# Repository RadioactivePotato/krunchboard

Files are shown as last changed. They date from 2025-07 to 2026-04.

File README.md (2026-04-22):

# NO LONGER UPDATE, CHECK OUT A NEWER VERSION [HERE](https://github.com/krunchiekrunch/krunchboard-90)

# krunchboard
A custom 80% ISO mechanical keyboard powered by a Raspberry Pi Pico with KMK

# Note

Prod V1 of the PCB has its I2C lines flipped for the 0.91" OLED Display and MCP23017

Firmware doesn't work yet

# About
I made this keyboard after I designed my [macropad](https://github.com/krunchiekrunch/krunchpad), and I thought this would be a fun project to do, I've also never owned a mechanical keyboard so maybe this is a good way to start?

# Images

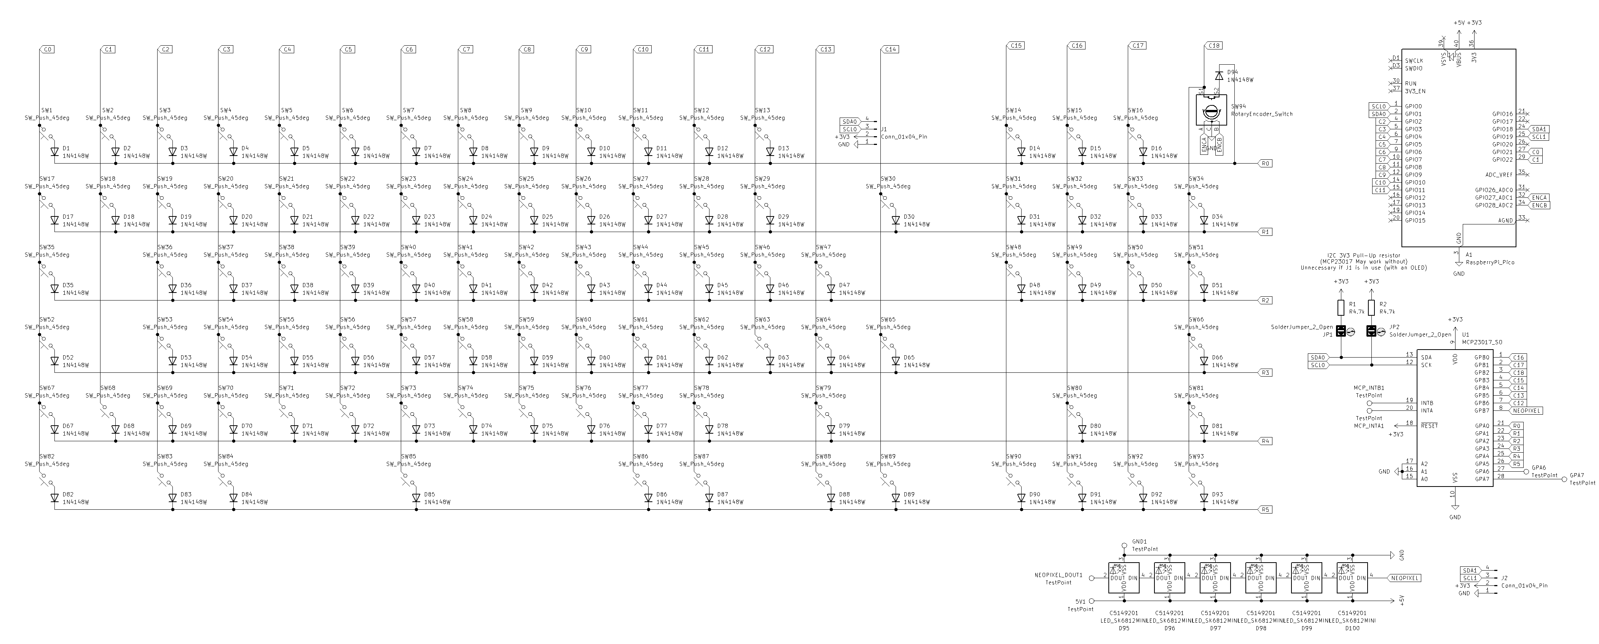
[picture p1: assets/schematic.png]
Schematic


| PCB | 3D View |
|-----|---|
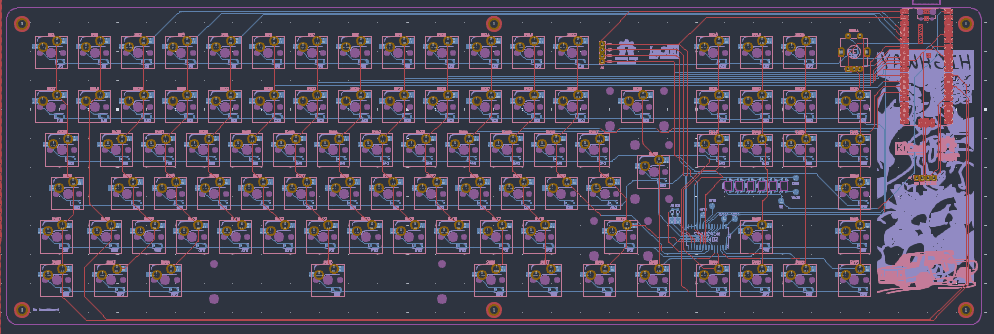
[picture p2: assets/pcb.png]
PCB
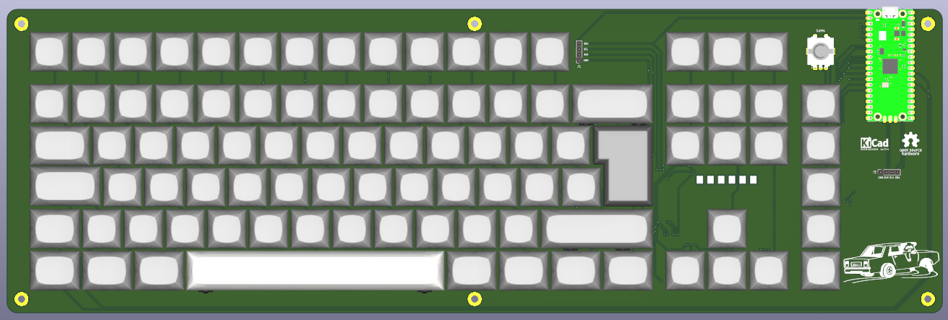
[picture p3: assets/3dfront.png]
3D-Front
|  |  |
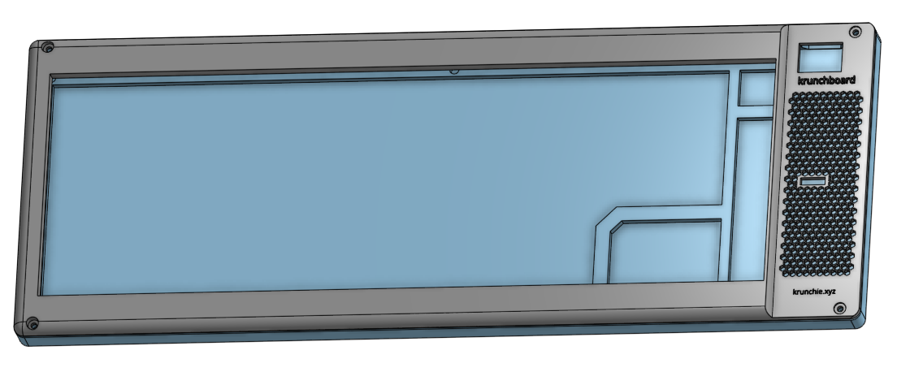
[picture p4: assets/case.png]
Case
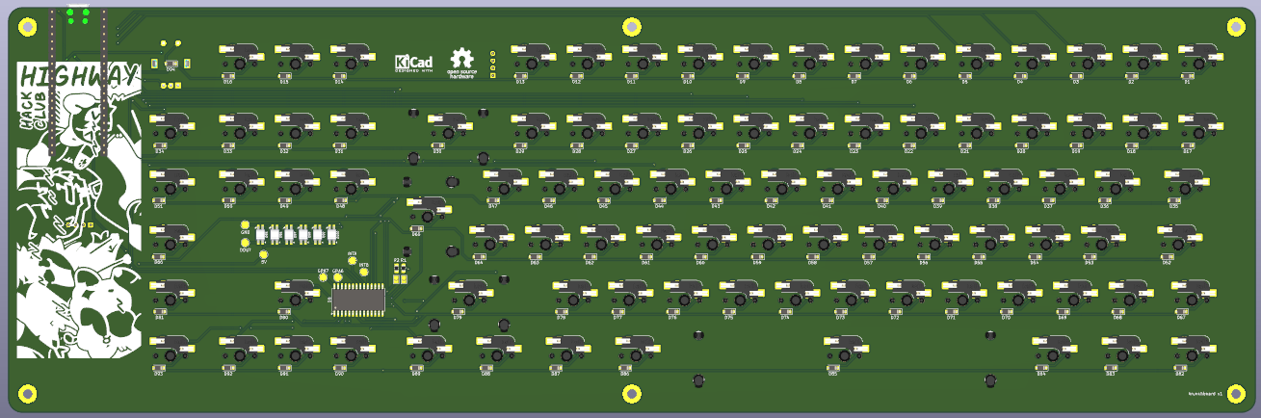
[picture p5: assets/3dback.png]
3D-Back
|  |  |

# Render

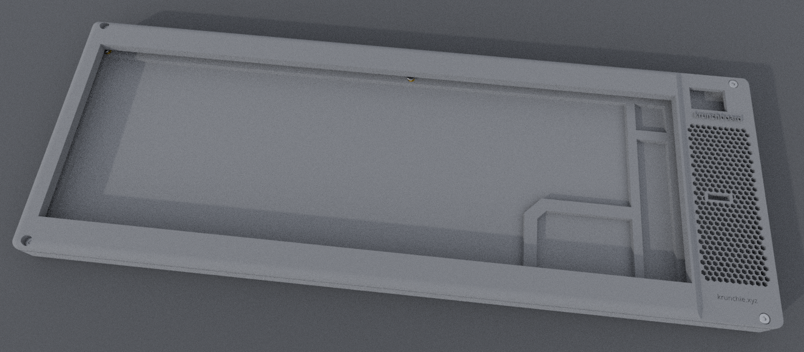
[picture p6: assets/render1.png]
Render1


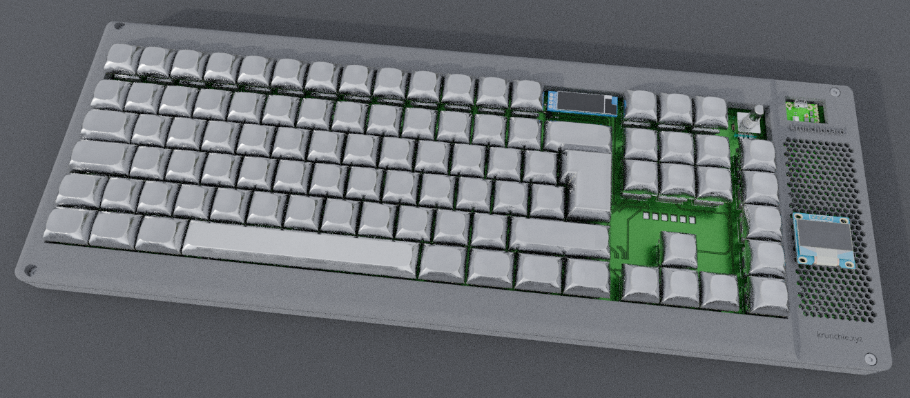
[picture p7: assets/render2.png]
Render2


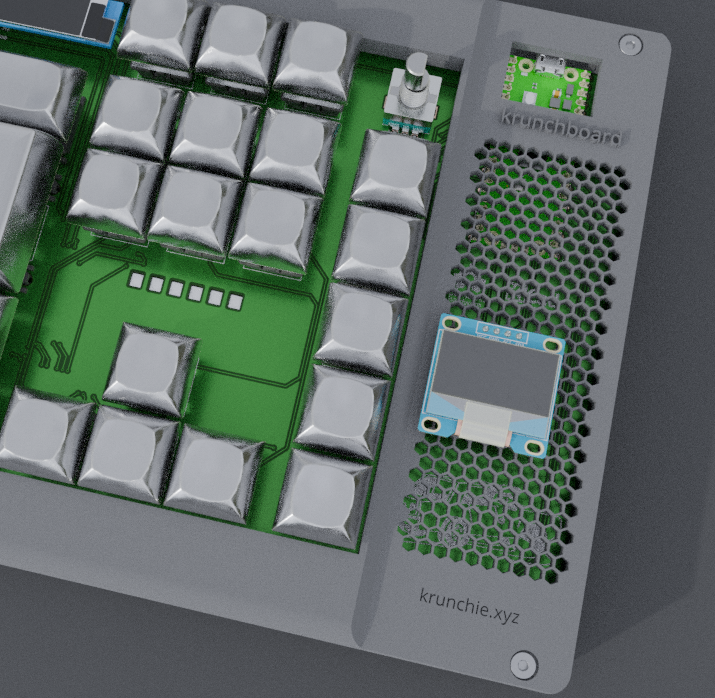
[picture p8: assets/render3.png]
Render3


# BOM
| Qty | Item | Notes | Cost (USD) | URL |
|-----|---|---|---|---|
| 1 | Raspberry Pi Pico | USB-C Clone | 2.30 | [AliExpress](https://www.aliexpress.com/item/1005006067365069.html) |
| 1 | EC11 Rotary Encoder | | 2.54 | [AliExpress](https://www.aliexpress.com/item/1005008413622715.html) |
| 1 | Rotary Encoder Knob | | 0.98 | [AliExpress](https://www.aliexpress.com/item/1005007951780072.html) |
| 92  | Kailh MX Hotswap Socket | Hotswapping for switches | 7.88 | [AliExpress](https://www.aliexpress.com/item/1005007476614771.html) |
| 1 | 0.91" OLED Display | | 2.06 | [AliExpress](https://www.aliexpress.com/item/1005007672413060.html) |
| 1 | 0.96" OLED Display | | 2.18 | [AliExpress](https://www.aliexpress.com/item/1005006985022252.html) |
| 1 | MX Stabilisers Set | For big keycaps | 4.37 | [AliExpress](https://www.aliexpress.com/item/1005009345248282.html) |
| 93  | 1N4148W Diode (SOD-123) | Already have | 0.50 | [LCSC](https://www.lcsc.com/product-detail/C42441811.html) |
| 1 | MCP23017 GPIO Expander (SOIC-28) | Already have | 1.94 | [LCSC](https://www.lcsc.com/product-detail/C629440.html) |
| 2 | 4 Slot 2.54mm Socket | Already have | 0.43 | [LCSC](https://www.lcsc.com/product-detail/C7509546.html) |
| 6 | SK6812MINI-E / SK6812E Neopixel | Already have | 0.74 | [LCSC](https://www.lcsc.com/product-detail/C5149201.html) |
| | | | | |
| 1 | Keycaps Set | | 13.94 | [AliExpress](https://www.aliexpress.com/item/1005009177442825.html) |
| 87  | Linear Key Switch | Main keyboard switches | 9.31 | [AliExpress](https://www.aliexpress.com/item/1005002378701948.html) |
| 5 | Tactile MX-Style Switch | Shortcut keys switches | 2.00 | [AliExpress](https://www.aliexpress.com/item/1005009249474760.html) |
| 6 | Sticky rubber feet | Antislip for keyboard | 1.26 | [AliExpress](https://www.aliexpress.com/item/1005006832476105.html) |
| | | | | |
| 12  | M3x5mmx4mm Heatset Inserts (W\*H)  | For mounting | 2.13 | [AliExpress](https://www.aliexpress.com/item/1005007640664497.html) |
| 12  | M3x5mm Screws | For case assembly | 2.44 | [AliExpress](https://www.aliexpress.com/item/1005006621501802.html) |
| | | | | |
| 1 | Solder Paste | Reflow soldering for SMD | 5.11 | [AliExpress](https://www.aliexpress.com/item/1005009377104599.htm) |
| 1 | Solder Wire | 50g | 3.32 | [AliExpress](https://www.aliexpress.com/item/1005008053204920.html) |
| | | | | |
| 1 | 3D Printed Case | print-legion postage (via royal mail) | 7.00 | print-legion |
| 1 | PCB | Shipping $12.89 | 41.79 | JLCPCB |
| | | | | |
| | | **Total AliExpress (GBP)** | **61.82**  | |
| | | **PCB and Case (GBP)** | **48.79**  | |
| | | Total (USD)** | **103.61** | |

A badge of a Cerberus and a raccoon laughing together, with the text "HIGHWAY" and "HACK CLUB" beside them.

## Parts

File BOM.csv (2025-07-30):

Qty | Item | Notes | Cost (USD) | URL
1 | Raspberry Pi Pico | USB-C Clone | 2.44 | https://www.aliexpress.com/item/1005006067365069.html
93 | 1N4148W Diode (SOD-123) | Switch matrix | 1.07 | https://www.aliexpress.com/item/4000558559509.html
1 | EC11 Rotary Encoder |  | 2.44 | https://www.aliexpress.com/item/1005008413622715.html
1 | Rotary Encoder Knob |  | 0.97 | https://www.aliexpress.com/item/1005007951780072.html
92 | Kailh MX Hotswap Socket | Hotswapping for switches | 7.46 | https://www.aliexpress.com/item/1005007476614771.html
1 | 0.91 inch OLED Display |  | 2.12 | https://www.aliexpress.com/item/1005007672413060.html
1 | 0.96 inch OLED Display |  | 2.18 | https://www.aliexpress.com/item/1005006985022252.html
1 | MX Stabilisers Set | For big keycaps | 8.50 | https://www.amazon.co.uk/gp/product/B0FGHP1QQN
1 | MCP23017 GPIO Expander (SOIC-28) | I will buy this myself | 1.62 | https://www.digikey.co.uk/en/products/detail/microchip-technology/MCP23017-E-SO/894271
2 | 4 Slot 2.54mm Socket (SMD) | I will buy this myself | 3.10 | https://www.digikey.co.uk/en/products/detail/samtec-inc/SSM-104-L-SV-BE/7859809
6 | SK6812MINI-E / SK6812E Neopixel | Already have some | 2.95 | https://www.digikey.co.uk/en/products/detail/adafruit-industries-llc/4960/14302512
1 | Keycaps Set |  | 13.44 | https://www.aliexpress.com/item/1005009177442825.html
87 | Linear Key Switch | Main keyboard switches | 9.84 | https://www.aliexpress.com/item/1005002378701948.html
5 | Tactile MX-Style Switch | Shortcut keys switches | 5.33 | https://www.amazon.co.uk/dp/B0DSJ21RDS
6 | Sticky rubber feet | Antislip for keyboard | 3.46 | https://www.amazon.co.uk/dp/B0DTGCM631
12 | M3x5mmx4mm Heatset Inserts (W*H) | For mounting | 2.92 | https://www.amazon.co.uk/dp/B0D1WVNW3G
12 | M3x4mm Screws | For case assembly | 4.53 | https://www.amazon.co.uk/dp/B0DRGVKT3R
1 | Solder Paste | Reflow soldering for SMD | 10.67 | https://www.amazon.co.uk/dp/B0DJX4D5BK
1 | Solder Wire | 50g | 3.32 | https://www.aliexpress.com/item/1005008053204920.html
1 | 3D Printed Case | print-legion postage (via royal mail) | 7.00 | print-legion
1 | PCB | Shipping $12.89 | 41.79 | JLCPCB
 |  | **Total AliExpress (GBP)** | **45.28**
 |  | **Total Amazon (GBP)** | **35.40**
 |  | **Total AliExpress + Amazon (GBP)** | **80.68**
 |  | **PCB and Case (GBP)** | **48.79**
 |  | Total (USD)** | **129.47**

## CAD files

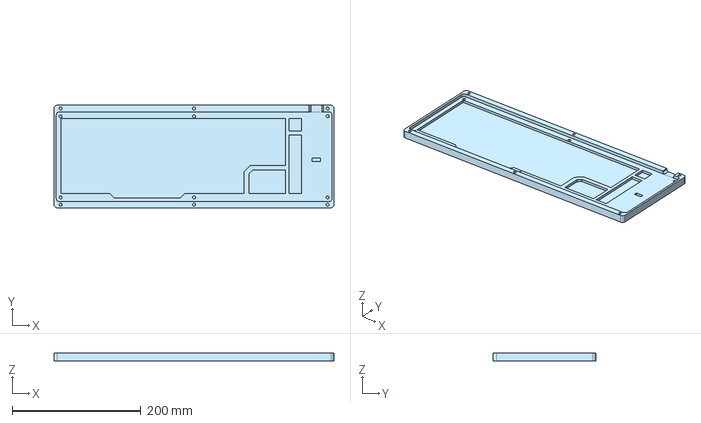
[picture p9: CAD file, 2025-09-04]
case-cad/v.1.3_krunchboard-case_bottom.step
434.2 x 159.1 x 12.0 mm

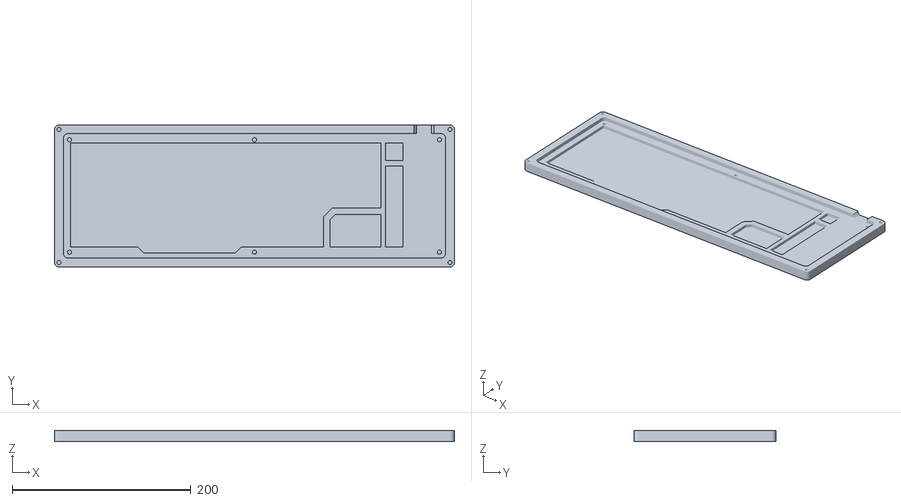
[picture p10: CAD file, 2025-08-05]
production/case/v1.2-3_krunchboard-case_bottom.stl
447.6 x 158.9 x 12.0

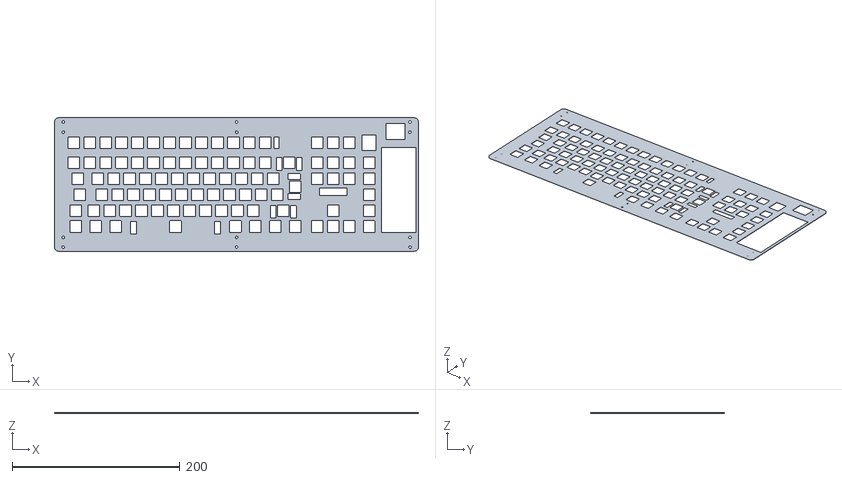
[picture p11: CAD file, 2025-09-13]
production/plate/v1.1_krunchboard-plate.stl
434.2 x 159.3 x 1.51

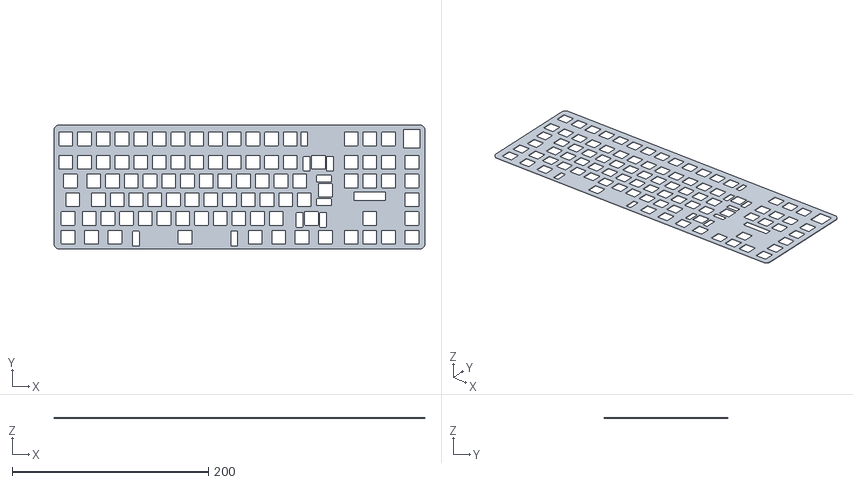
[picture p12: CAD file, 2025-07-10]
production/plate/v1/v1-krunchboard-plate.stl
377.7 x 126.1 x 1.51

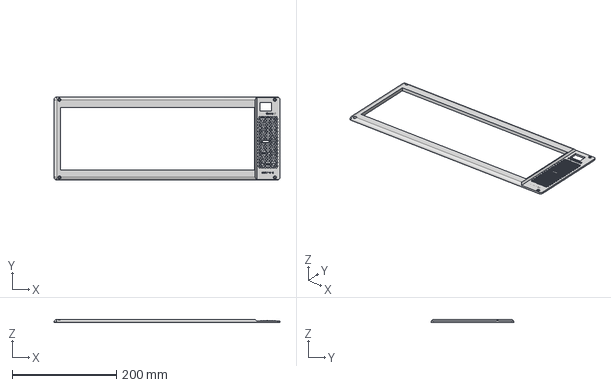
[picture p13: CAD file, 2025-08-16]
case-cad/v1.3_krunchboard-case_top.step
434.2 x 159.1 x 6.20 mm

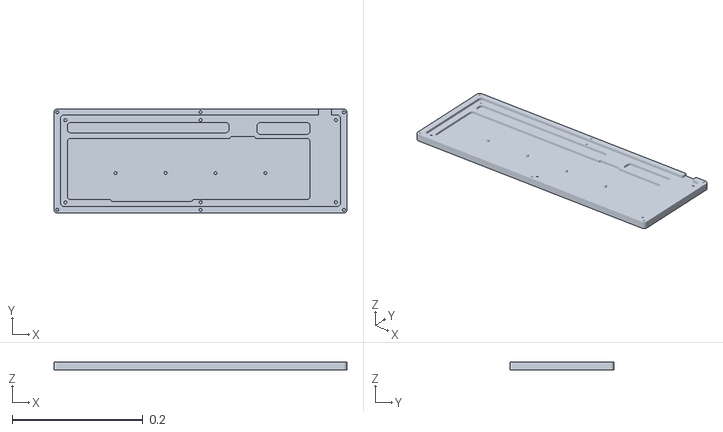
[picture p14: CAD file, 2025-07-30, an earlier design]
production/case/v1.1/v1.1_krunchboard-case.stl
0.448 x 0.159 x 0.0115

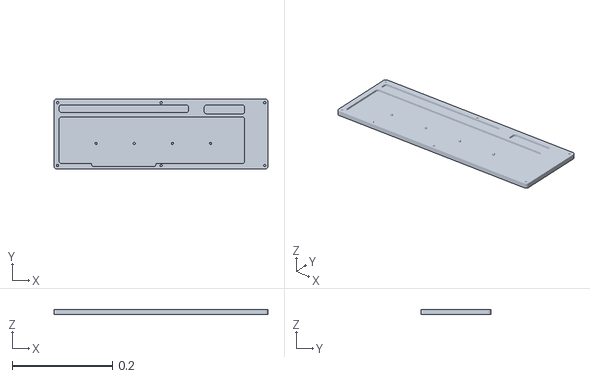
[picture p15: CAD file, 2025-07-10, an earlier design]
production/case/v1/v1-krunchboard-case.stl
0.428 x 0.14 x 0.009

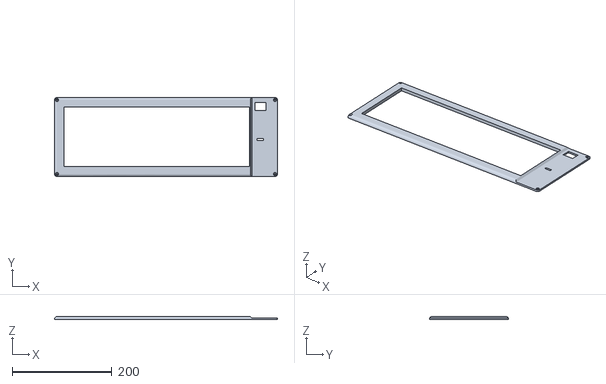
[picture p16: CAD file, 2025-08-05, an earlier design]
production/case/v1.2/v1.2_krunchboard-case_top.stl
447.6 x 158.9 x 6.20

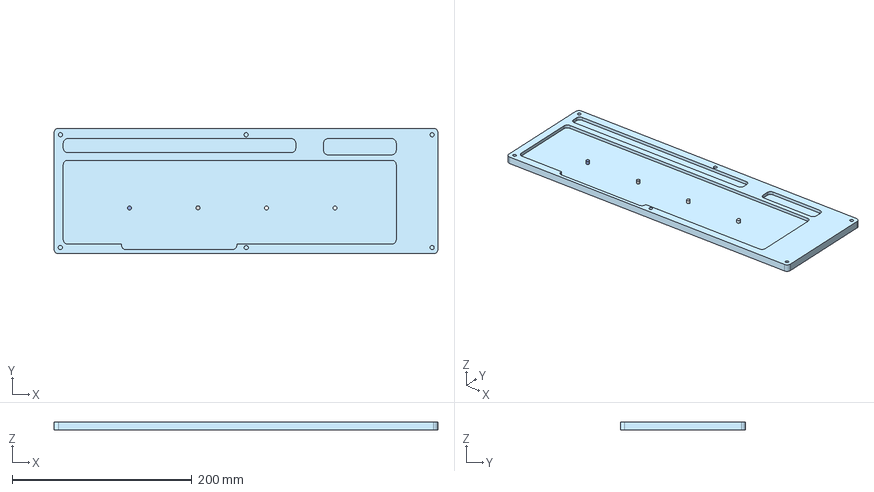
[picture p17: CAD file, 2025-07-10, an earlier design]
case-cad/v1_krunchboard-case.step
427.6 x 139.7 x 9.00 mm

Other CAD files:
production/case/v1.3/v.1.3_krunchboard-case_bottom.stl
production/case/v1.3/v1.3_krunchboard-case_top.stl
case-cad/v1.1_krunchboard-case.step
case-cad/v.1.2_krunchboard-case_bottom.step
case-cad/v1.2_krunchboard-case_top.step

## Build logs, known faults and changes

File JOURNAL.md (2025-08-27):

---
title: "krunchboard"
author: "slack: krunch"
description: "A 85% ISO mechanical keyboard powered by Raspberry Pi Pico"
created_at: "2025-06-26"
---

# Total time spent: 26 hours

# June 26th - Made the schematic (3 hours)

<details>
<summary>Click to expand</summary>

Made the basic schematic with the ISO105 layout, but without the number pad.

Had to use a gpio expander because I was running low on pins

I used [keyboard-layout-editor.com](https://keyboard-layout-editor.com) and [kbfirmware.com](https://kbfirmware.com) to help.





**Time spent this session: 3 hours**

</details>

# June 27th - Placed the components (4 hours)

<details>
<summary>Click to expand</summary>

Followed this diagram



Spent quite a while trying to get the key switches to not overlap, but [this video](https://www.youtube.com/watch?v=8WXpGTIbxlQ&t=864s) helped a ton!

I switched the diodes and gpio expander from THT to SMT, it might be harder to solder but it's going ot look much better!

## Progress





## Finished the PCB layout







**Time spent this session: 4 hours**

</details>

# June 28 - Redid the entire schematic (3.5 hours)

<details>
<summary>Click to expand</summary>

I decided to make the function key row closer to the number row, i also switched the oled from 0.96" to 0.91".

I added 5 programmable macro keys on the right and moved the volume knob to the top right.

Unfortunately I had to redo the schematic and pcb because when I changed the size of the keycaps, the column number also changed as well, which basically moved all of the keys to a new column









**Time spent this session: 3.5 hours**

</details>

# June 30th - Placed the diodes ...again (2 hours)

<details>
<summary>Click to expand</summary>

I rotated all the symbols for key switches in the schematic by 180 degrees so that the wiring would be much cleaner, I originally tried to make a script that does that in one go, but I gaved up and decided to just rotate them all manually 

I also placed all the diodes on the PCB, and whilst wiring up the columns, I realised that the row traces will block the connection



And since the hotswap sockets and diodes are both surface mounted, I'd have to create a via at all the column connections



Pretty sure I can just use the footprint that have the holes plated, that way I can just wire the column to the THT pad, I'll figure that out next time.



**Time spent this session: 2 hours**

</details>

# July 8-9th - Started wiring the rows and columns (1.5 hours)

<details>
<summary>Click to expand</summary>

Like I mentioned in the last journal entry, i ran in to a "issue" where I would need to create multiple vias in order to properly wire the columns which I thought doesn't look as good, so I found a hotswap footprint with the hole being plated, this way, it can serve as a via (through hole) itself, and I won't have to place down multiple vias

| Before | After |
|---|---|
|  |  |

## NO VIAS!

Since I am now using a different footprint, I had to reassign the 3D models to the switches which took quite a while

Once I finished with that, I began wiring up the rows and columns!



It's now 00:15am  lol, I'll continue wiring up the rows tomorrow and will replace the neopixel footprint with a reverse mounted one.

**Time spent this session: 1.5 hours**

</details>

# July 9th - "Finished" PCB and Case (4 hours)

<details>
<summary>Click to expand</summary>

Today I finished wiring up the rows and columns of the PCB (I haven't connected it to the Pico yet since I still haven't decided the final location of the Pico).

I also added 6 M3 mounting holes for it to attach to the case and replaced the SK6812-Mini-E footprint with a reverse mountable one.





| Front | Back |
|---|---|
|  |  |

## Case Design

I designed it in OnShape, I started by placing the PCB layout (from 3D viewer) on the sketch, and then drew the slots for the components in the back of the PCB to sit in, I also added a few "beams" to support the middle of the PCB.

| - | - |
|---|---|
|  |  |



**Time spent this session: 4 hours**

</details>

# July 10th - Plate, BOM, and Files (4 hours)

<details>
<summary>Click to expand</summary>

Today I writtened the BOM in the README file, I also imported all the files necessary to the GitHub repo.

I used [keyboard-layout-editor.com](https://keyboard-layout-editor.com) and [kbplate.ai03.com](https://kbplate.ai03.com) to generate the DXF image, then I imported it to KiCad's `Edge.Cuts` layer. Since I have an OLED display and a rotary encoder, I had to manually draw the cutouts for it.



I was originally going to use FR4 for the plate, but I soon realised that would be too expensive (about $60 incl. shipping), so I resorted to 3D printing. I exported the PCB as stl and imported it to Bambu studio, where I cut the model in half and it was able to fit on the print bed. I also did this for the case since it was also too big.

I will finish up the final bits of wiring on the main PCB and begin the firmware work (KMK). I should be able to submit this project over the weekend (July 12-13).




**Time spent this session: 4 hours**

</details>

# July 11 - Art and Firmware (4 hours)

<details>
<summary>Click to expand</summary>

Today I created the firmware, a large portion of the code is based on the ANAVI macropad 12's firmware, I followed my schematic and [the keycode list](https://github.com/KMKfw/kmk_firmware/blob/main/docs/en/keycodes.md) to code the keymaps.

I also finished up all the wiring on the pcb, It took quite a while and I had to move some of the traces which was originally going to the Pico, but now it's moved to the MCP23017.

Also used maybe too many vias lol





To fill in the blank space in the back of the PCB, I converted the Highway artwork to KiCad silkscreen.



And then I added some silkscreen art to the front as well, and then added a 0.96" OLED display.



And that's the whole project done!

</details>

# August 16 - Case V1.3 (3 hours)

<details>
<summary>Click to expand</summary>

I wanted to fill in the empty space on the right side of the case, I decided that I would add some hexagon holes to allow the user to be able to see into the PCB, where the silkscreen art is.

I originally decided to just use a [pattern plugin for OnShape](https://forum.onshape.com/discussion/16660/hexagonal-pattern), but it was too confusing and won't let me put the pattern too close to each other. So I decided to place the holes manually,

The holes will be 0.5mm apart which should be printable by 3D printers.

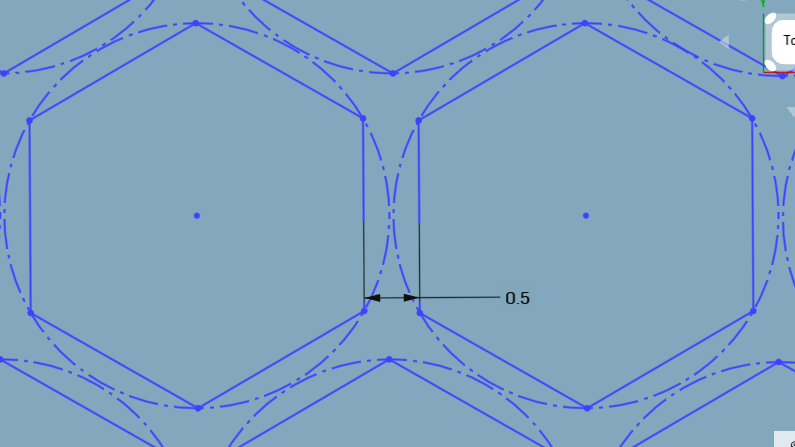
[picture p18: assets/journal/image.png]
gap


render3

</details>

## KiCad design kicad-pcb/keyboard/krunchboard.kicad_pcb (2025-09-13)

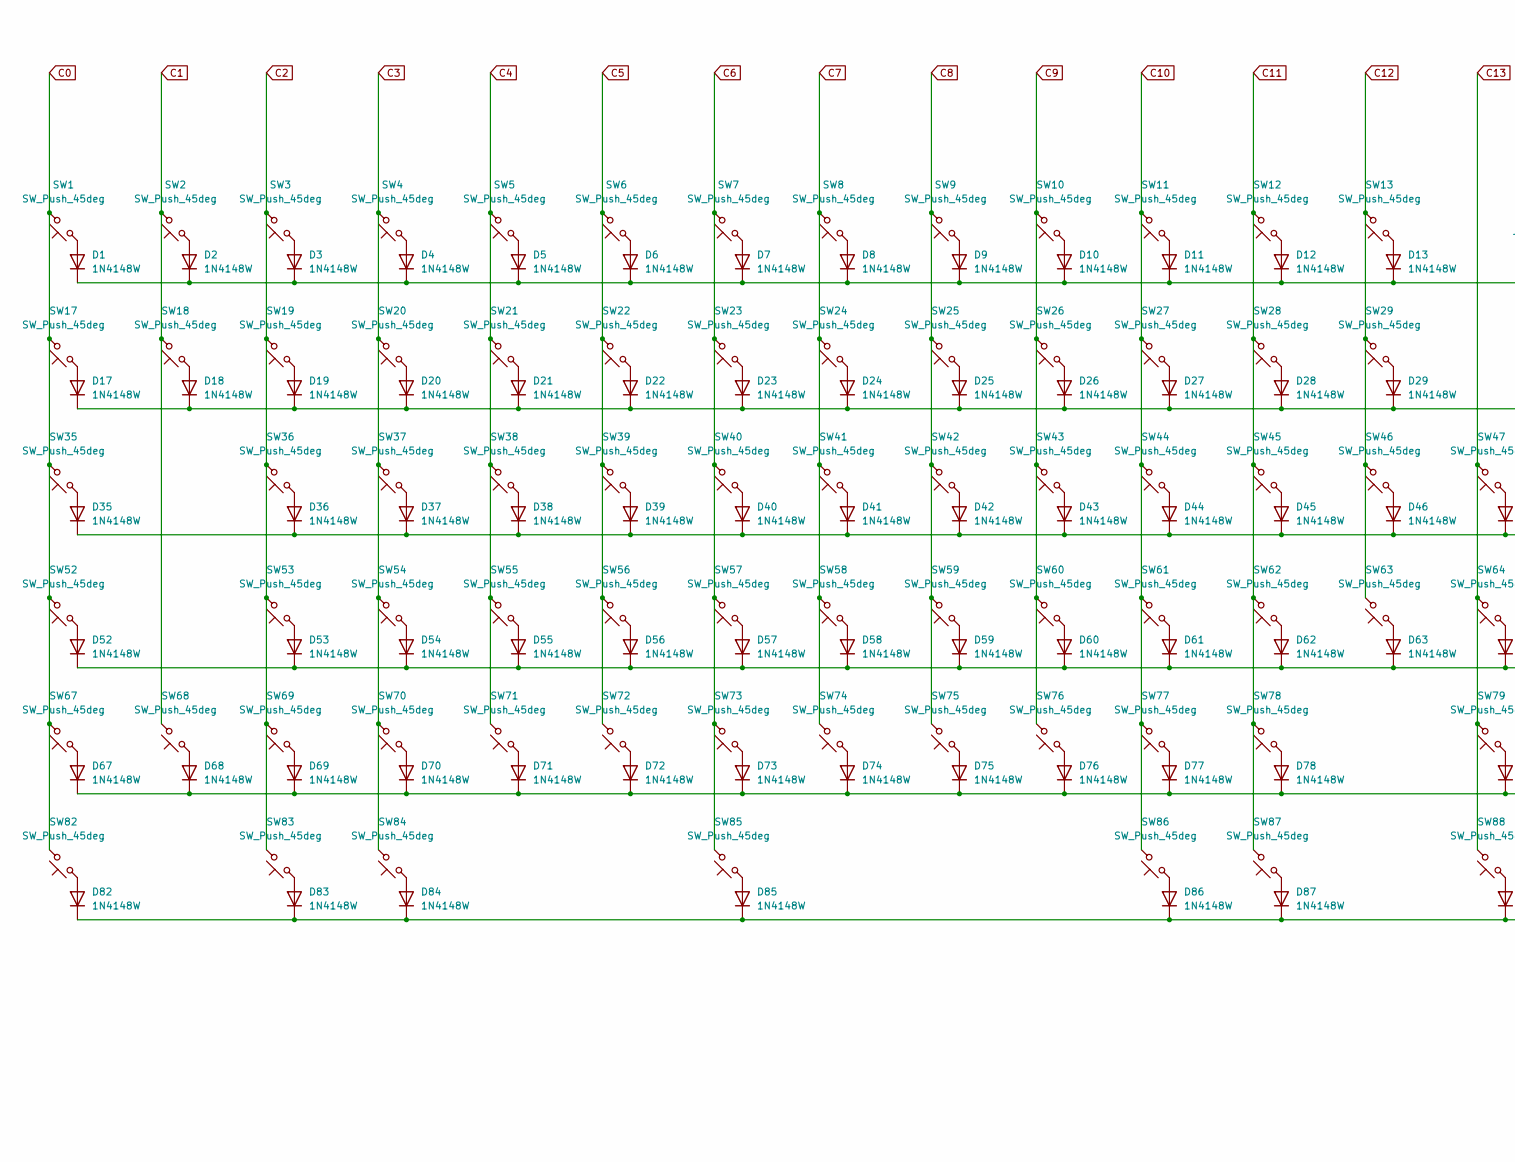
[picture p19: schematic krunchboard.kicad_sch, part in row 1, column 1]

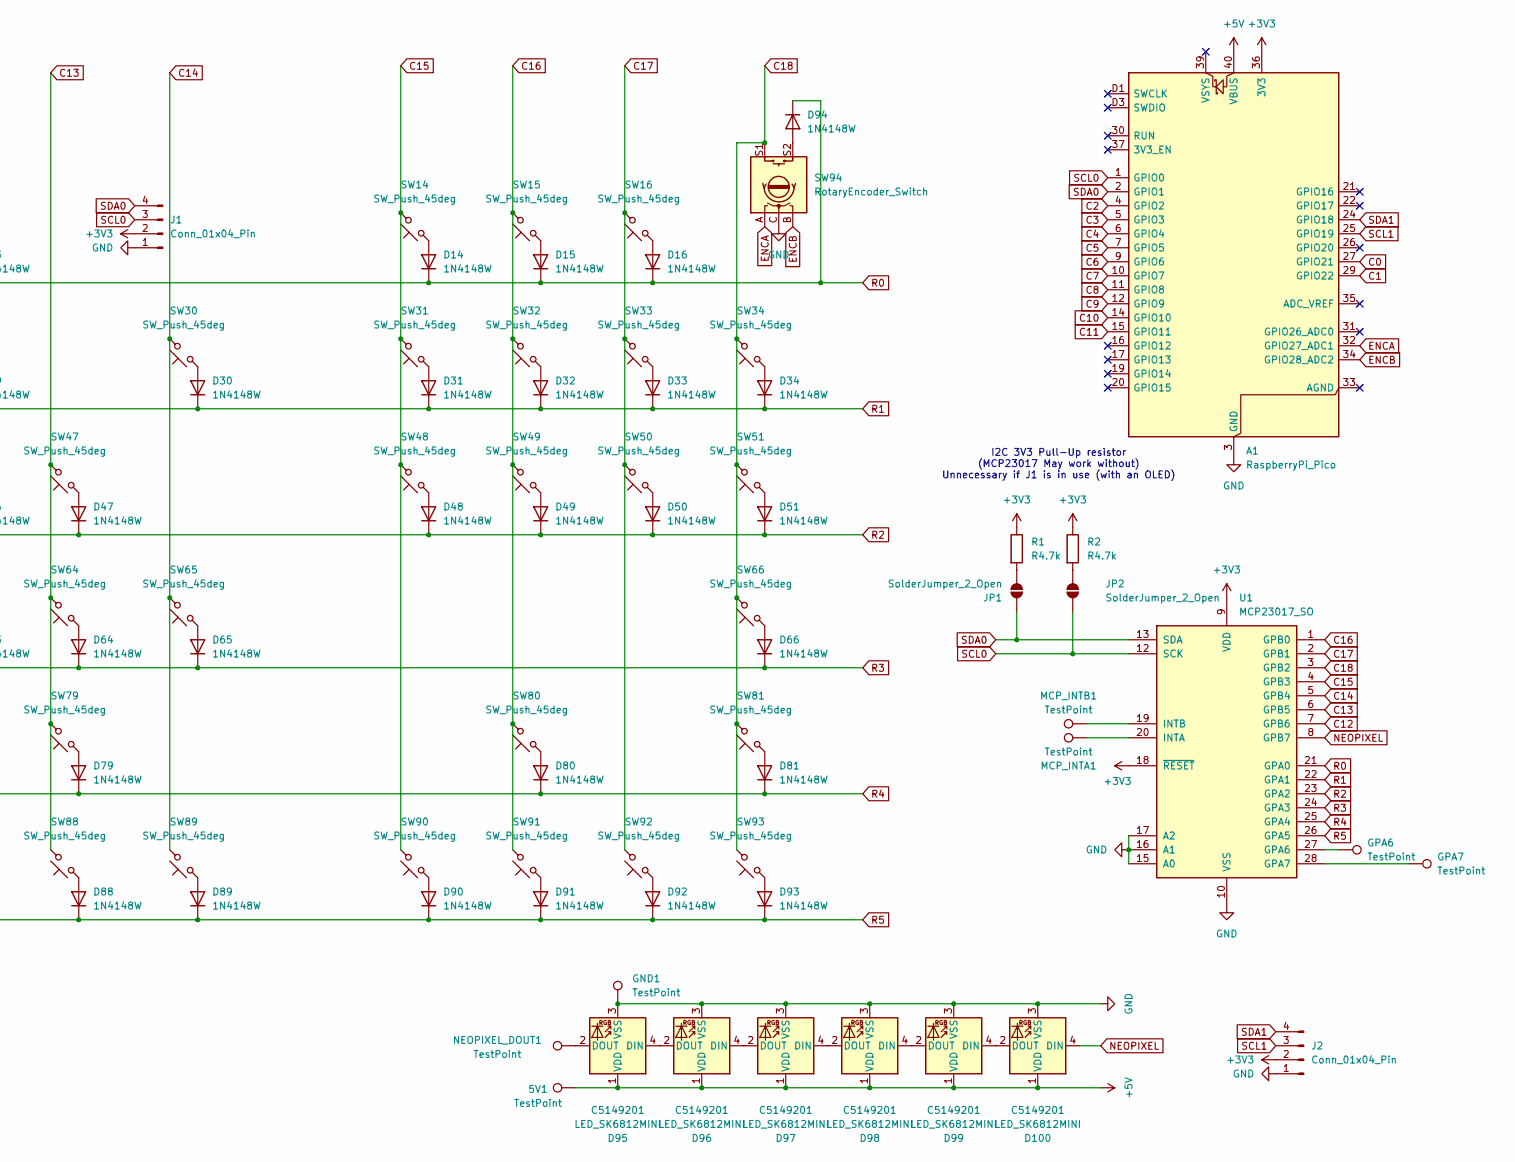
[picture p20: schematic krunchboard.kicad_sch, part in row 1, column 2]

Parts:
5V1: TestPoint; TestPoint_Pad_D2.5mm
A1: RaspberryPi_Pico; RaspberryPi_Pico_SMD_HandSolder
D1, D2, D3, D4, D5, D6, D7, D8, D9, D10, D11, D12, D13, D14, D15, D16, D17, D18, D19, D20, D21, D22, D23, D24, D25, D26, D27, D28, D29, D30, D31, D32, D33, D34, D35, D36, D37, D38, D39, D40, D41, D42, D43, D44, D45, D46, D47, D48, D49, D50, D51, D52, D53, D54, D55, D56, D57, D58, D59, D60, D61, D62, D63, D64, D65, D66, D67, D68, D69, D70, D71, D72, D73, D74, D75, D76, D77, D78, D79, D80, D81, D82, D83, D84, D85, D86, D87, D88, D89, D90, D91, D92, D93, D94: 1N4148W; D_SOD-123
D95, D96, D97, D98, D99, D100: LED_SK6812MINI; SK6812-MINI-E; LCSC C5149201
GND1: TestPoint; TestPoint_Pad_D2.5mm
GPA6, GPA7: TestPoint; TestPoint_Pad_D2.5mm
J1, J2: Conn_01x04_Pin; PinSocket_1x04_P2.54mm_Vertical
JP1, JP2: SolderJumper_2_Open; SolderJumper-2_P1.3mm_Open_TrianglePad1.0x1.5mm
MCP_INTA1: TestPoint; TestPoint_Pad_D2.5mm
MCP_INTB1: TestPoint; TestPoint_Pad_D2.5mm
NEOPIXEL_DOUT1: TestPoint; TestPoint_Pad_D2.5mm
R1, R2: R4.7k; R_0805_2012Metric_Pad1.20x1.40mm_HandSolder
SW1, SW2, SW3, SW4, SW5, SW6, SW7, SW8, SW9, SW10, SW11, SW12, SW13, SW14, SW15, SW16, SW17, SW18, SW19, SW20, SW21, SW22, SW23, SW24, SW25, SW26, SW27, SW28, SW29, SW31, SW32, SW33, SW34, SW36, SW37, SW38, SW39, SW40, SW41, SW42, SW43, SW44, SW45, SW46, SW47, SW48, SW49, SW50, SW51, SW53, SW54, SW55, SW56, SW57, SW58, SW59, SW60, SW61, SW62, SW63, SW64, SW66, SW68, SW69, SW70, SW71, SW72, SW73, SW74, SW75, SW76, SW77, SW78, SW80, SW81, SW90, SW91, SW92, SW93: SW_Push_45deg; Hotswap_MX_Plated_1.00u
SW30: SW_Push_45deg; Hotswap_MX_Plated_2.00u
SW35: SW_Push_45deg; Hotswap_MX_Plated_1.50u
SW52: SW_Push_45deg; Hotswap_MX_Plated_1.75u
SW65: SW_Push_45deg; Hotswap_MX_Plated_ISOEnter
SW67, SW82, SW83, SW84, SW86, SW87, SW88, SW89: SW_Push_45deg; Hotswap_MX_Plated_1.25u
SW79: SW_Push_45deg; Hotswap_MX_Plated_2.75u
SW85: SW_Push_45deg; Hotswap_MX_Plated_6.25u
SW94: RotaryEncoder_Switch; RotaryEncoder_Alps_EC11E-Switch_Vertical_H20mm
U1: MCP23017_SO; SOIC-28W_7.5x17.9mm_P1.27mm

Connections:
+3V3: A1.36 (3V3), J1.2, J2.2, R1.1, R2.1, U1.9 (VDD), U1.18 (~RESET)
+5V: 5V1.1, A1.40 (VBUS), D95.1 (VDD), D96.1 (VDD), D97.1 (VDD), D98.1 (VDD), D99.1 (VDD), D100.1 (VDD)
C0: A1.27 (GPIO21), SW1.2, SW17.2, SW35.2, SW52.2, SW67.2, SW82.2
C1: A1.29 (GPIO22), SW2.2, SW18.2, SW68.2
C2: A1.4 (GPIO2), SW3.2, SW19.2, SW36.2, SW53.2, SW69.2, SW83.2
C3: A1.5 (GPIO3), SW4.2, SW20.2, SW37.2, SW54.2, SW70.2, SW84.2
C4: A1.6 (GPIO4), SW5.2, SW21.2, SW38.2, SW55.2, SW71.2
C5: A1.7 (GPIO5), SW6.2, SW22.2, SW39.2, SW56.2, SW72.2
C6: A1.9 (GPIO6), SW7.2, SW23.2, SW40.2, SW57.2, SW73.2, SW85.2
C7: A1.10 (GPIO7), SW8.2, SW24.2, SW41.2, SW58.2, SW74.2
C8: A1.11 (GPIO8), SW9.2, SW25.2, SW42.2, SW59.2, SW75.2
C9: A1.12 (GPIO9), SW10.2, SW26.2, SW43.2, SW60.2, SW76.2
C10: A1.14 (GPIO10), SW11.2, SW27.2, SW44.2, SW61.2, SW77.2, SW86.2
C11: A1.15 (GPIO11), SW12.2, SW28.2, SW45.2, SW62.2, SW78.2, SW87.2
C12: SW13.2, SW29.2, SW46.2, SW63.2, U1.7 (GPB6)
C13: SW47.2, SW64.2, SW79.2, SW88.2, U1.6 (GPB5)
C14: SW30.2, SW65.2, SW89.2, U1.5 (GPB4)
C15: SW14.2, SW31.2, SW48.2, SW90.2, U1.4 (GPB3)
C16: SW15.2, SW32.2, SW49.2, SW80.2, SW91.2, U1.1 (GPB0)
C17: SW16.2, SW33.2, SW50.2, SW92.2, U1.2 (GPB1)
C18: SW34.2, SW51.2, SW66.2, SW81.2, SW93.2, SW94.S1, U1.3 (GPB2)
ENCA: A1.32 (GPIO27_ADC1), SW94.A
ENCB: A1.34 (GPIO28_ADC2), SW94.B
GND: A1.3 (GND), A1.8 (GND), A1.13 (GND), A1.18 (GND), A1.23 (GND), A1.28 (GND), A1.38 (GND), A1.D2 (GND), D95.3 (VSS), D96.3 (VSS), D97.3 (VSS), D98.3 (VSS), D99.3 (VSS), D100.3 (VSS), GND1.1, J1.1, J2.1, SW94.C, U1.10 (VSS), U1.15 (A0), U1.16 (A1), U1.17 (A2)
NEOPIXEL: D100.4 (DIN), U1.8 (GPB7)
unnamed: D1.2 (A), SW1.1
unnamed: D2.2 (A), SW2.1
unnamed: D3.2 (A), SW3.1
unnamed: D4.2 (A), SW4.1
unnamed: D5.2 (A), SW5.1
unnamed: D6.2 (A), SW6.1
unnamed: D7.2 (A), SW7.1
unnamed: D8.2 (A), SW8.1
unnamed: D9.2 (A), SW9.1
unnamed: D10.2 (A), SW10.1
unnamed: D11.2 (A), SW11.1
unnamed: D12.2 (A), SW12.1
unnamed: D13.2 (A), SW13.1
unnamed: D14.2 (A), SW14.1
unnamed: D15.2 (A), SW15.1
unnamed: D16.2 (A), SW16.1
unnamed: D17.2 (A), SW17.1
unnamed: D18.2 (A), SW18.1
unnamed: D19.2 (A), SW19.1
unnamed: D20.2 (A), SW20.1
unnamed: D21.2 (A), SW21.1
unnamed: D22.2 (A), SW22.1
unnamed: D23.2 (A), SW23.1
unnamed: D24.2 (A), SW24.1
unnamed: D25.2 (A), SW25.1
unnamed: D26.2 (A), SW26.1
unnamed: D27.2 (A), SW27.1
unnamed: D28.2 (A), SW28.1
unnamed: D29.2 (A), SW29.1
unnamed: D30.2 (A), SW30.1
unnamed: D31.2 (A), SW31.1
unnamed: D32.2 (A), SW32.1
unnamed: D33.2 (A), SW33.1
unnamed: D34.2 (A), SW34.1
unnamed: D35.2 (A), SW35.1
unnamed: D36.2 (A), SW36.1
unnamed: D37.2 (A), SW37.1
unnamed: D38.2 (A), SW38.1
unnamed: D39.2 (A), SW39.1
unnamed: D40.2 (A), SW40.1
unnamed: D41.2 (A), SW41.1
unnamed: D42.2 (A), SW42.1
unnamed: D43.2 (A), SW43.1
unnamed: D44.2 (A), SW44.1
unnamed: D45.2 (A), SW45.1
unnamed: D46.2 (A), SW46.1
unnamed: D47.2 (A), SW47.1
unnamed: D48.2 (A), SW48.1
unnamed: D49.2 (A), SW49.1
unnamed: D50.2 (A), SW50.1
unnamed: D51.2 (A), SW51.1
unnamed: D52.2 (A), SW52.1
unnamed: D53.2 (A), SW53.1
unnamed: D54.2 (A), SW54.1
unnamed: D55.2 (A), SW55.1
unnamed: D56.2 (A), SW56.1
unnamed: D57.2 (A), SW57.1
unnamed: D58.2 (A), SW58.1
unnamed: D59.2 (A), SW59.1
unnamed: D60.2 (A), SW60.1
unnamed: D61.2 (A), SW61.1
unnamed: D62.2 (A), SW62.1
unnamed: D63.2 (A), SW63.1
unnamed: D64.2 (A), SW64.1
unnamed: D65.2 (A), SW65.1
unnamed: D66.2 (A), SW66.1
unnamed: D67.2 (A), SW67.1
unnamed: D68.2 (A), SW68.1
unnamed: D69.2 (A), SW69.1
unnamed: D70.2 (A), SW70.1
unnamed: D71.2 (A), SW71.1
unnamed: D72.2 (A), SW72.1
unnamed: D73.2 (A), SW73.1
unnamed: D74.2 (A), SW74.1
unnamed: D75.2 (A), SW75.1
unnamed: D76.2 (A), SW76.1
unnamed: D77.2 (A), SW77.1
unnamed: D78.2 (A), SW78.1
unnamed: D79.2 (A), SW79.1
unnamed: D80.2 (A), SW80.1
unnamed: D81.2 (A), SW81.1
unnamed: D82.2 (A), SW82.1
unnamed: D83.2 (A), SW83.1
unnamed: D84.2 (A), SW84.1
unnamed: D85.2 (A), SW85.1
unnamed: D86.2 (A), SW86.1
unnamed: D87.2 (A), SW87.1
unnamed: D88.2 (A), SW88.1
unnamed: D89.2 (A), SW89.1
unnamed: D90.2 (A), SW90.1
unnamed: D91.2 (A), SW91.1
unnamed: D92.2 (A), SW92.1
unnamed: D93.2 (A), SW93.1
unnamed: D94.2 (A), SW94.S2
unnamed: D95.4 (DIN), D96.2 (DOUT)
unnamed: D95.2 (DOUT), NEOPIXEL_DOUT1.1
unnamed: D96.4 (DIN), D97.2 (DOUT)
unnamed: D97.4 (DIN), D98.2 (DOUT)
unnamed: D98.4 (DIN), D99.2 (DOUT)
unnamed: D99.4 (DIN), D100.2 (DOUT)
unnamed: JP1.1 (A), R1.2
unnamed: JP2.1 (A), R2.2
unnamed: GPA6.1, U1.27 (GPA6)
unnamed: GPA7.1, U1.28 (GPA7)
unnamed: MCP_INTA1.1, U1.20 (INTA)
unnamed: MCP_INTB1.1, U1.19 (INTB)
R0: D1.1 (K), D2.1 (K), D3.1 (K), D4.1 (K), D5.1 (K), D6.1 (K), D7.1 (K), D8.1 (K), D9.1 (K), D10.1 (K), D11.1 (K), D12.1 (K), D13.1 (K), D14.1 (K), D15.1 (K), D16.1 (K), D94.1 (K), U1.21 (GPA0)
R1: D17.1 (K), D18.1 (K), D19.1 (K), D20.1 (K), D21.1 (K), D22.1 (K), D23.1 (K), D24.1 (K), D25.1 (K), D26.1 (K), D27.1 (K), D28.1 (K), D29.1 (K), D30.1 (K), D31.1 (K), D32.1 (K), D33.1 (K), D34.1 (K), U1.22 (GPA1)
R2: D35.1 (K), D36.1 (K), D37.1 (K), D38.1 (K), D39.1 (K), D40.1 (K), D41.1 (K), D42.1 (K), D43.1 (K), D44.1 (K), D45.1 (K), D46.1 (K), D47.1 (K), D48.1 (K), D49.1 (K), D50.1 (K), D51.1 (K), U1.23 (GPA2)
R3: D52.1 (K), D53.1 (K), D54.1 (K), D55.1 (K), D56.1 (K), D57.1 (K), D58.1 (K), D59.1 (K), D60.1 (K), D61.1 (K), D62.1 (K), D63.1 (K), D64.1 (K), D65.1 (K), D66.1 (K), U1.24 (GPA3)
R4: D67.1 (K), D68.1 (K), D69.1 (K), D70.1 (K), D71.1 (K), D72.1 (K), D73.1 (K), D74.1 (K), D75.1 (K), D76.1 (K), D77.1 (K), D78.1 (K), D79.1 (K), D80.1 (K), D81.1 (K), U1.25 (GPA4)
R5: D82.1 (K), D83.1 (K), D84.1 (K), D85.1 (K), D86.1 (K), D87.1 (K), D88.1 (K), D89.1 (K), D90.1 (K), D91.1 (K), D92.1 (K), D93.1 (K), U1.26 (GPA5)
SCL0: A1.1 (GPIO0), J1.3, JP2.2 (B), U1.12 (SCK)
SCL1: A1.25 (GPIO19), J2.3
SDA0: A1.2 (GPIO1), J1.4, JP1.2 (B), U1.13 (SDA)
SDA1: A1.24 (GPIO18), J2.4

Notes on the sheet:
I2C 3V3 Pull-Up resistor (MCP23017 May work without) Unnecessary if J1 is in use (with an OLED)

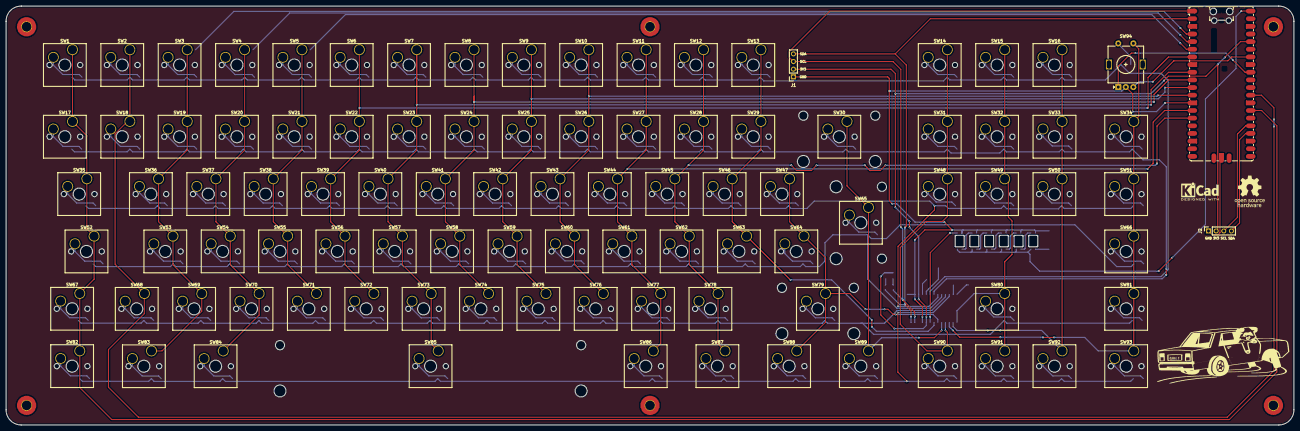
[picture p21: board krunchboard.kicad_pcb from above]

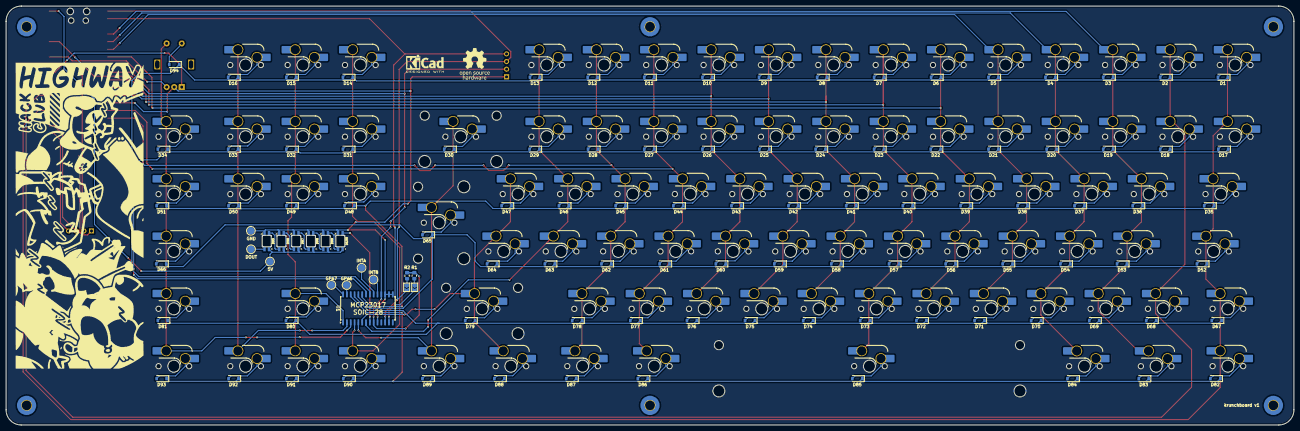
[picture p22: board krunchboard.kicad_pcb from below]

Board: 2 copper layers, 427.6 x 139.1 mm, 211 parts (113 on the bottom side), 141 nets.

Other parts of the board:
logo1, logo1#2: KiCad-Logo2_5mm_SilkScreen

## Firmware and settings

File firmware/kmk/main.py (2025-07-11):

import board
import busio

from kmk.kmk_keyboard import KMKKeyboard
from kmk.scanners import DiodeOrientation
from kmk.extensions.display import Display, TextEntry
from kmk.extensions.display.ssd1306 import SSD1306
from kmk.extensions.media_keys import MediaKeys
from kmk.extensions.RGB import RGB, AnimationModes
from kmk.keys import KC
from kmk.modules.mcp23017 import MCP23017

i2c0 = busio.I2C(scl=board.GP1, sda=board.GP0)
i2c1 = busio.I2C(scl=board.GP1, sda=board.GP0)

mcp = MCP23017(i2c0, address=0x20)

keyboard = KMKKeyboard()

# 0.91" oled
display32 = Display(
    display=SSD1306(i2c=i2c0, address=0x3C),
    entries=[TextEntry(text='Hello World 32')],
    height=32,
)
keyboard.extensions.append(display32)

# 0.96" oled
display64 = Display(
    display=SSD1306(i2c=i2c1, address=0x3C),
    entries=[TextEntry(text='Hello World 64')],
    height=64,
)
keyboard.extensions.append(display64)

# pico neopixel
frontglow = RGB(
    pixel_pin=board.GP25,
    num_pixels=1,
    val_limit=100,
    val_default=25,
    animation_mode=AnimationModes.RAINBOW,
)
keyboard.extensions.append(frontglow)

# sk6812e
underglow = RGB(
    pixel_pin=mcp.P8,
    num_pixels=6,
    val_limit=100,
    val_default=25,
    animation_mode=AnimationModes.RAINBOW,
)
keyboard.extensions.append(underglow)

keyboard.col_pins = (
    board.GP21, # C0
    board.GP22,
    board.GP2,
    board.GP3,
    board.GP4,
    board.GP5,
    board.GP6,
    board.GP7,
    board.GP8,
    board.GP9,
    board.GP10,
    board.GP11,
    mcp.P1, # C12
    mcp.P2, # C13
    mcp.P3, # C14
    mcp.P4, # C15
    mcp.P5, # C16
    mcp.P6, # C17
    mcp.P7, # C18
)

keyboard.row_pins = (
    mcp.P21, # R0
    mcp.P22,
    mcp.P23,
    mcp.P24,
    mcp.P25,
    mcp.P26, # R5
)

keyboard.diode_orientation = DiodeOrientation.COL2ROW

keyboard.extensions.append(MediaKeys())

keyboard.keymap = [
    [KC.ESC, KC.F1, KC.F2, KC.F3, KC.F4, KC.F5, KC.F6, KC.F7, KC.F8, KC.F9, KC.F10, KC.F11, KC.F12, KC.NO, KC.NO, KC.PSCR, KC.SCRLK, KC.PAUSE, KC.MUTE],
    [KC.GRAVE, KC.N1, KC.N2, KC.N3, KC.N4, KC.N5, KC.N6, KC.N7, KC.N8, KC.N9, KC.N0, KC.MINUS, KC.EQUAL, KC.NO, KC.BSPACE, KC.INSERT, KC.HOME, KC.PGUP, KC.NO],
    [KC.TAB, KC.NO, KC.Q, KC.W, KC.E, KC.R, KC.T, KC.Y, KC.U, KC.I, KC.O, KC.P, KC.LBRACKET, KC.RBRACKET, KC.NO, KC.DEL, KC.END, KC.PGDN, KC.NO], 
    [KC.KCAP, KC.NO, KC.A, KC.S, KC.D, KC.F, KC.G, KC.H, KC.J, KC.K, KC.L, KC.SCLN, KC.QUOTE, KC.HASH, KC.ENTER, KC.NO, KC.NO, KC.NO, KC.NO],
    [KC.LSHIFT, KC.BSLASH, KC.Z, KC.X, KC.C, KC.V, KC.B, KC.N, KC.M, KC.COMMA, KC.DOT, KC.SLASH, KC.NO, KC.RSHIFT, KC.NO, KC.NO, KC.UP, KC.NO, KC.NO],
    [KC.LCTRL, KC.NO, KC.LGUI, KC.LALT, KC.NO, KC.NO, KC.SPACE, KC.NO, KC.NO, KC.NO, KC.RALT, KC.RGUI, KC.NO, KC.APP, KC.RCTRL, KC.LEFT, KC.DOWN, KC.RIGHT, KC.NO]
]

if __name__ == '__main__':
    keyboard.go()

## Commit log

2025-07-10 Fixed BOM broken URL
2025-07-10 cad+pcb files / repo setup / assets
    [krunchboard.kicad_sch, v1-krunchboard-baseplate.step, v1-krunchboard-baseplate.stl]
2025-07-10 bom update
2025-07-10 switched some items from amazon to aliexpress
2025-07-10 splitted case in half
    [v1-krunchboard-baseplate-left.stl, v1-krunchboard-baseplate-right.stl]
2025-07-10 readme formatting for images + case image
2025-07-10 plate files
    [krunchboard-plate.kicad_pcb, krunchboard-plate.kicad_sch, krunchboard.kicad_sch]
2025-07-10 replaced the half cases and added neopixel to bom
    [v1-krunchboard-baseplate-left.stl, v1-krunchboard-baseplate-right.stl]
2025-07-10 updated plate files
    [krunchboard-plate.kicad_pcb]
2025-07-10 Added PCB to BOM
2025-07-10 edited the plate
    [krunchboard-plate.kicad_pcb, v1-krunchboard-plate.stl]
2025-07-10 even more plate updates
    [v1-krunchboard-baseplate-left.stl, v1-krunchboard-baseplate-right.stl, v1-krunchboard-baseplate.stl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]
2025-07-11 Replaced the pi pico with a usbc clone
2025-07-11 pcb files, photos, and added 0.96 oled to firmware
    [krunchboard.kicad_sch]
2025-07-11 bill's csv
    [BOM.csv]
2025-07-11 updated bom pricing
2025-07-12 new bill's csv
    [BOM.csv]
2025-07-12 swapped 0.96 oled power pins to [GND,VCC,SCL,SDA]
    [krunchboard.kicad_sch]
2025-07-22 replaced pin sockets with smd version
    [krunchboard.kicad_pcb, krunchboard.kicad_sch]
2025-07-30 switched mounting styles, updated pcb, plate, and case
    [krunchboard-plate.kicad_pcb, krunchboard-plate.kicad_sch, krunchboard.kicad_pcb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]
2025-07-30 updated 1x04 2.54mm socket url in bom
2025-07-30 updated bom error
    [BOM.csv]
2025-08-05 case v1.2, added 3d models to pcb, adjusted plate
    [SA_ISO_Enter.STL, heatset-insert.stl, krunchboard-case-bottom.stl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]
2025-08-16 case v1.3
    [v1.2_krunchboard-case_bottom.stl, v1.2_krunchboard-case_top.stl, v1.3_krunchboard-case_top.step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]
2025-08-27 BOM price update
2025-08-27 aug 16 journal
    [v.1.2-3_krunchboard-case_bottom.step, v1.2-3_krunchboard-case_bottom.stl]
2025-08-27 changed solder paste source
2025-09-04 updated pcb - switched oled socket from smd to tht, added hole for tht socket in case, adjusted pcb vias and silkscreen, added testpoints to pcb
    [krunchboard.kicad_pcb, krunchboard.kicad_sch, v.1.2_krunchboard-case_bottom.step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]
2025-09-13 final v1 pcb revision, plate update
    [SA_ISO_Enter.STL, heatset-insert.stl, krunchboard-case-bottom.stl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]
2025-09-25 updated schem, pcb, 3d images
